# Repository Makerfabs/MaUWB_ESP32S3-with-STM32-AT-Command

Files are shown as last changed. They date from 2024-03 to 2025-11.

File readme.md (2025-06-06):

# MaUWB_ESP32S3 with STM32 AT Command

```

Version:    V1.1
Author:     Vincent
Create Date:    2024/3/12
Note:

        2024/9/24  V1.1: MaUWB(v1.1.1).HEX is released to support simultaneous data transmission for ranging. 

```


[toc]

# Makerfabs

[Makerfabs home page](https://www.makerfabs.com/)

[Makerfabs Wiki](https://wiki.makerfabs.com/)

# MaUWB_ESP32S3 with STM32 AT Command
## Intruduce

Product Link ：[MaUWB_ESP32S3 with STM32 AT Command]() 

Wiki Link : []()

The latest UWB module that solves multiple anchors& tags mutual conflicts, support max 8 Anchors + 64 tags in application, to create a multi-anchor multi-tag positioning system, and add the ability to set the Anchor antenna delay

## Feature

- DW3000 with PA, max range 500M
- Precision 0.5M(in range 100m)
- Support 8 anchors+ 64 Tags application

# Code

## AT Command Usage

Please refer to the AT Command manual for detailed use.

hardware\Makerfabs UWB AT Module AT Command Manual(v1.0.5).pdf

### Initial configuration

You are advised to use serial_test.ino to configure the UWB AT module.
Each time you configure the UWB AT module, follow the following configuration sequence:

```C 

AT?

//Test whether the serial port communication is normal

AT+RESTORE

//Restore factory Settings

AT+SETCFG=(x1),(x2),(x3),(x4)
// Such as: AT+SETCFG=0,1,0,1

//Set the role and frequency
//More on that later

AT+SETCAP=10,15

//Set the capacity and send time slot

AT+SETRPT=1

// Turn on automatic reporting

AT+SAVE

// Save

AT+RESTART

// Restart

```

### Set the role and frequency

AT+SETCFG=(x1),(x2),(x3),(x4)

Parameter description

x1: Device ID(Note: Base station 0-7, label 0-63)

x2: Device role (0: tag /1: base station)

x3: device air speed (0:850K/1:6.8M, default :6.8M)

x4: Range filtering enabled (0: off /1: on)

Generally, 850K is used and distance filtering is turned on.

```c
//Example
//A0
AT+SETCFG=0,1,0,1

//A1
AT+SETCFG=1,1,0,1

//A2
AT+SETCFG=2,1,0,1

//A3
AT+SETCFG=3,1,0,1

//T0
AT+SETCFG=0,0,0,1

//T1
AT+SETCFG=1,0,0,1

//T2
AT+SETCFG=2,0,0,1

//T3
AT+SETCFG=3,0,0,1

//T4
AT+SETCFG=4,0,0,1

//T5
AT+SETCFG=5,0,0,1

```

## Compiler Options

- Use type-c use cable connect USB-TTL to PC.
- Select "ESP32S3 DEV Module"

Libraries:
- Use 2.0.0   Wire
- Use 1.11.7   Adafruit_GFX_Library
- Use 1.14.4   Adafruit_BusIO
- Use 2.0.0   SPI
- Use 2.5.7   Adafruit_SSD1306

## Example

### esp32_at

Factory firmware, reset the UWB AT module and set it to Tag 0.

# AT Module Firmware Update

Connect ST-Link to PC.

Open STM32 ST-LINK Utility.
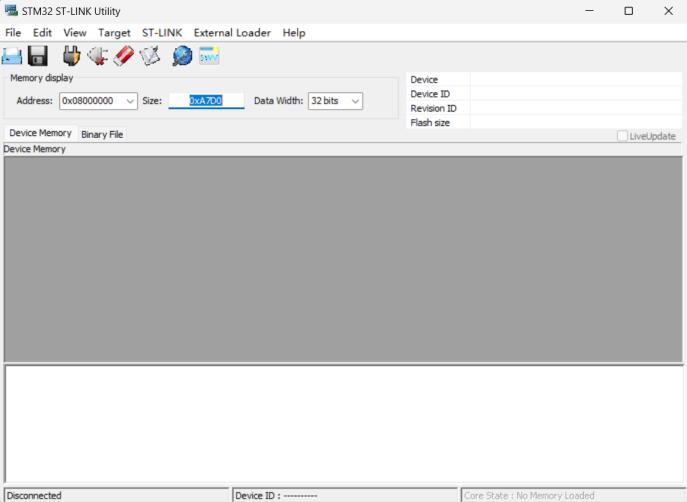
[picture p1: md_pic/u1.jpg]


Open "Target/Settings", it should display ST-Link Serial Number.
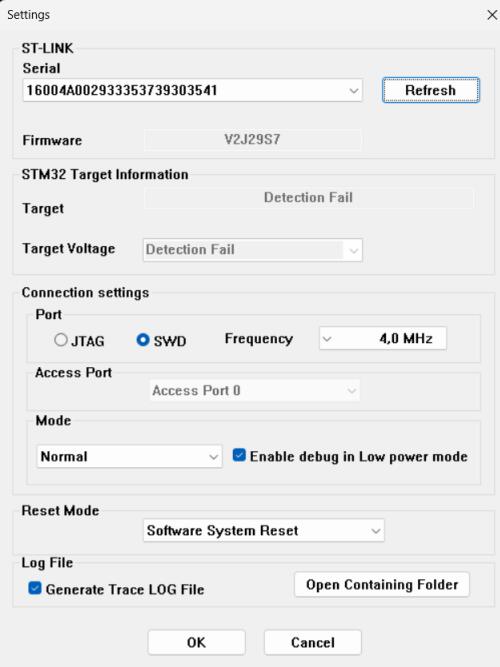
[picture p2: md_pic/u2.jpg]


Close the window, back to main page.

Connect ST-Link and MaUWB.

And use TypeC cable power on MaUWB, the power of ST-Link is not enough.

Like this:

|ST-LINK|3v3|clk|dio|gnd|
|----|----|----|----|----|
|UWB_AT|3.3v|swclk|swdio|gnd|

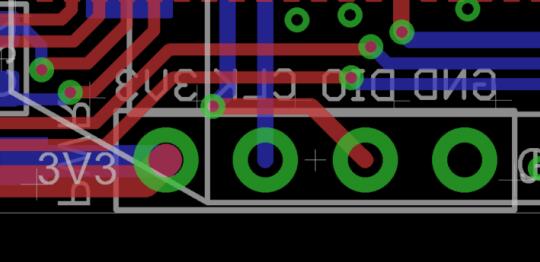
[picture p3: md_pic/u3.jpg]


Click "connect to target", it should be display device type. And click "Program verify".

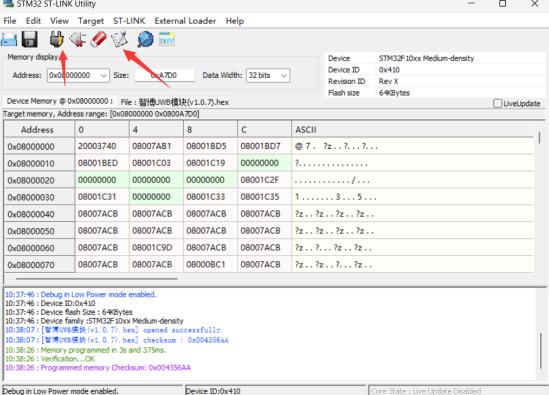
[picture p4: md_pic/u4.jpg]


Select hex file, click "START" to download.

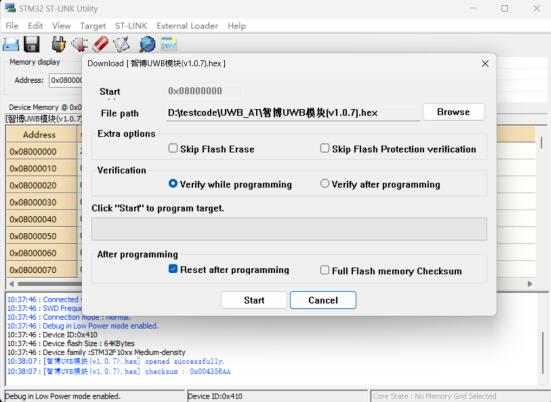
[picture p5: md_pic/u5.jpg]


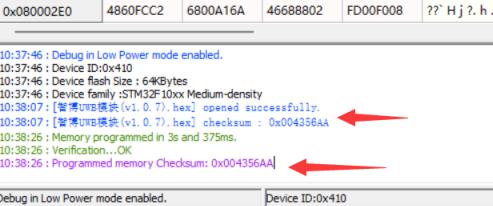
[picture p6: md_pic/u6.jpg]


# STM32 Pin Map

STM32F103T8U6

|Index|STM32|PINOUT|Function|
|----|----|----|----|
|1|PA0|DW_RSTn|Reset pin. Active Low Output.|
|2|PA4|DW_CSn|SPI chip select|
|3|PA5|DW_SLK|SPI clock|
|4|PA6|DW_MISO|SPI data output|
|5|PA7|DW_MOSI|SPI data input.|
|6|PA8|DW_EXTON|External device enable. Asserted during wake up process and held active until device enters sleep mode. Can be used to control external DC-DC converters or other circuits that are not required when the device is in sleep mode so as to minimize power consumption.|
|7|PB0|DW_wakeup|When asserted into its active high state, the WAKEUP pin brings the DW3000 out of SLEEP or DEEPSLEEP states into operational mode|
|8|PB5|DW_IRQn|Interrupt Request output from the DW3000 to the host processor. By default IRQ is an active-high output but may be configured to be active low if required. For correct operation in SLEEP and DEEPSLEEP modes it should be configured for active high operation. This pin will float in SLEEP and DEEPSLEEP states and may cause spurious interrupts unless pulled low. When the IRQ functionality is not being used the pin may be reconfigured as a general purpose I/O line, GPIO8.|
|10|PA1|LED_RUN|Indicator output pin|
|11|PA9|USART1_TX|
|12|PA10|USART1_RX|
|13|PA13|SWDIO|
|14|PA14|SWCLK|

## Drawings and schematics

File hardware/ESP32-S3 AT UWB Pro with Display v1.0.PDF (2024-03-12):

## USB

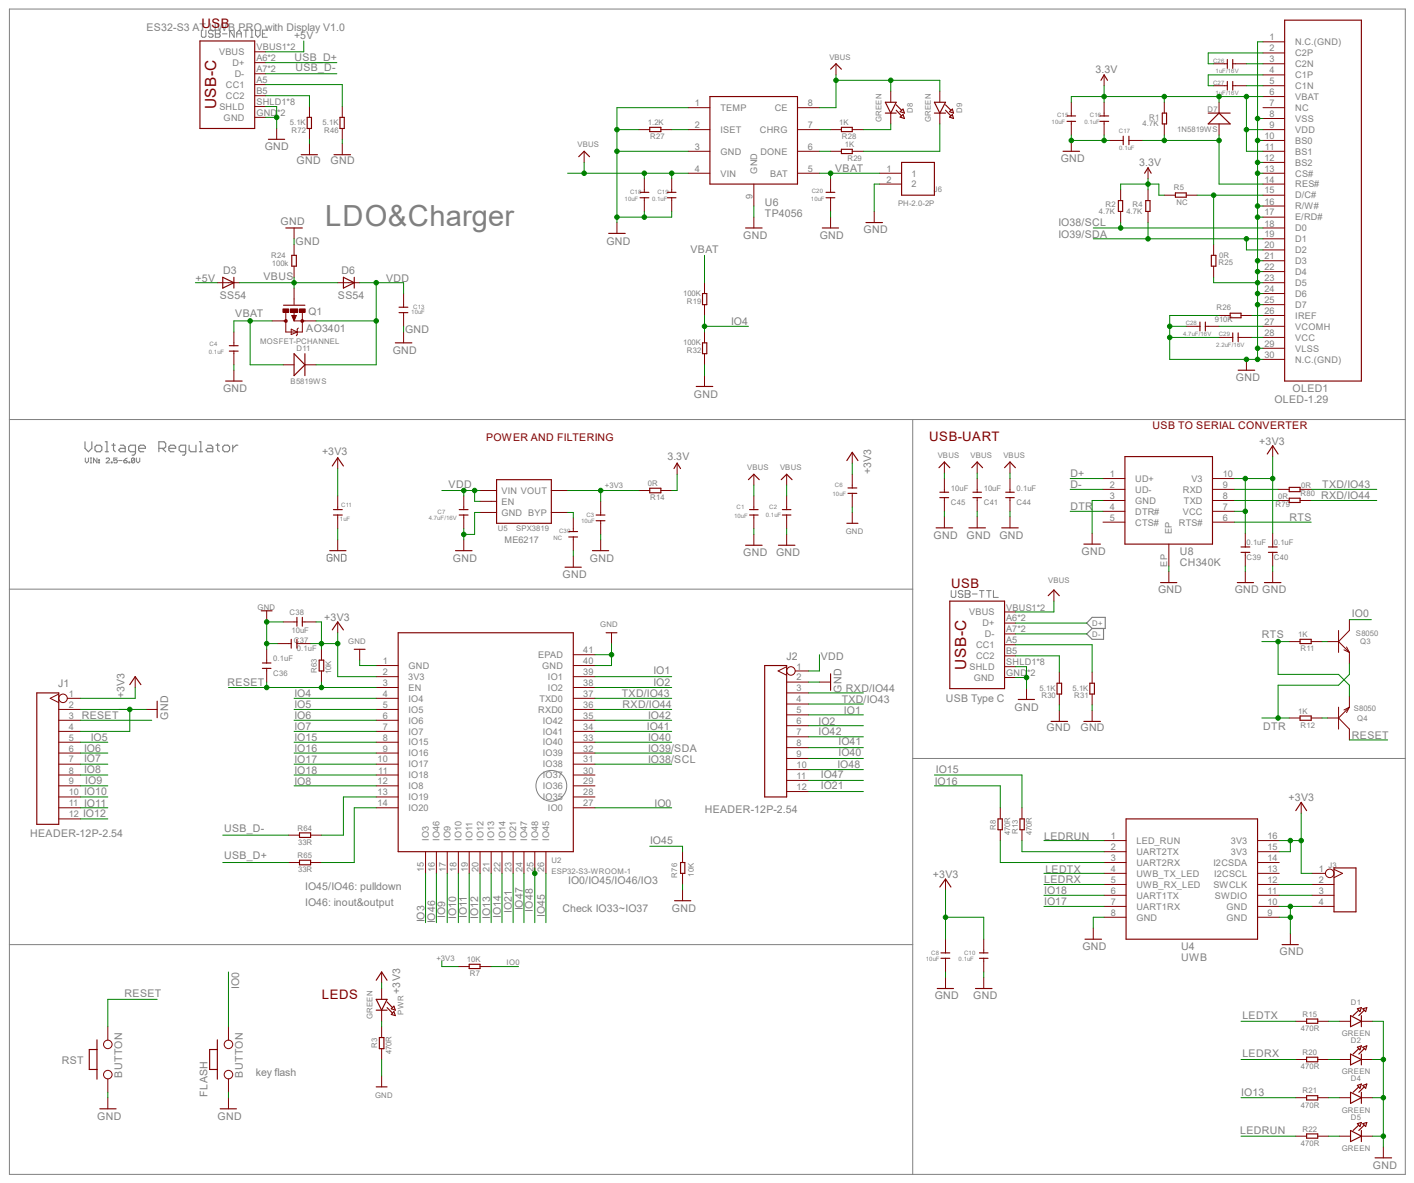
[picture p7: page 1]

ES32-S3 AT UWB PRO with Display V1.0

USB TO SERIAL CONVERTER USB⁻C USB⁻C

D1 19
D2 20

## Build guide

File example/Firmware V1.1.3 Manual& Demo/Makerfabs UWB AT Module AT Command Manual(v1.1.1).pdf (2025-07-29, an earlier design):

# Makerfabs UWB AT Module

# AT Command Manual

V1.1.1

Author：Yuki

Time：2025/07/29

Date | Versions | Description | Author
20230815 | v1.0.0 | Introduction to Use & Function | Jerry
20230823 | V1.0.1 | 1) Correct clerical errors 2) Anchor&Tag Software integration 3) Improve the Run Led pin description 4) Improve the Tx Led pin description 5) Improve the Rx Led pin description 6) Improved UART2 RX /RESET /WAKEUP pin description | Jerry
20230829 | V1.0.2 | 1) Add frequency option for 850K rate 2) Modify the boot log 3) Modify command，AT+SETCFG 4) Modify command，AT+GETCFG? 5) Modify command，AT+RANGE | Jerry
20230926 | V1.0.3 | 1) Improve documentation 2) Add hardware application circuits | Jerry
20230926 | V1.0.4 | 1) Added package size diagram | Jerry
20231013 | V1.0.5 | First edition of translation | Vincent
20240227 | V1.0.6 | The maximum number of labels increased to 64 | Vincent
20240315 | V1.0.7 | second edition of translation | Carla
20240920 | V1.0.8 | 1)Modify command，AT+SETCAP 2)Modify command，AT+GETCAP 3)Add command，AT+SETPOW | Yuki

| | 4)Add command，AT+GETPOW? 5)Add command，AT+DATA 6)Add command，AT+RDATA
20250227 | V1.0.9 | 1)Add command，AT+SETPAN 2)Add command，AT+GETPAN? | Yuki
20250707 | V1.1.0 | 1)Firmware MaUWB(v1.1.3) add functions: Anchor capacity expanded from 8 to unlimited, supporting multi-zone positioning. (Tags can now automatically detect and select the 8 nearest Anchors from a larger pool of deployed Anchors) 2)Modify command，AT+RANGE 3)Add command note， AT+GETCAP/ AT+GETCAP? 4)Add command note，AT+SETCFG / AT+GETCFG? 5)Add command default value，AT+GETCFG? / AT+GETANT? / AT+GETCAP? / AT+GETRPT? / AT+GETPOW? / AT+GETPAN? | Yuki
20250729 | V1.1.1 | Modify the error description to change the supported number of Anchors to "unlimited". | Yuki

Contents

# 1 Product description

## 1.1 Introduction

This module describes the high-precision real-time positioning module developed by our company based on Qorvo DW3000 series chips. The module integrates MCU and all RF circuits, antennas, power management and clock circuits. The module can be quickly configured and used

by AT command. The target readers are software and hardware engineers, UWB learners and users. This module is based on TOF (TWR) two-sided distance measurement and a variety of filtering algorithms to achieve distance calculation. After combination and collocation between multiple modules, it can be adapted to most of the location application scenarios, which is convenient for users to learn and research and rapid product application. Its ranging accuracy may be less than 10cm; And the module supports data transfer rates of up to 6.8Mbps. 1.2 Feature

1) Comply with IEEE802.15.4-2011 ultra-wideband standard;
2) Easy to integrate without additional RF design;
3) Support CH5 (6489.6MHZ) RF band;
4) Strong resistance to multi-path fading;
5) Two modes of data transmission rate of 850kbps and 6.8Mbps;
6) The maximum packet length is 1023 bytes, which meets the application requirements of high data volume exchange;
7) The system supports unlimited Anchor 64 tags. 8) The module supports free configuration of refresh rate, up to 100Hz;
9) Module serial port communication baud rate 115200;
10) Module (Tag) deep hibernation working current as low as 35uA, working current 34mA;
11) Support AT command;

## 1.3 Functional block diagram

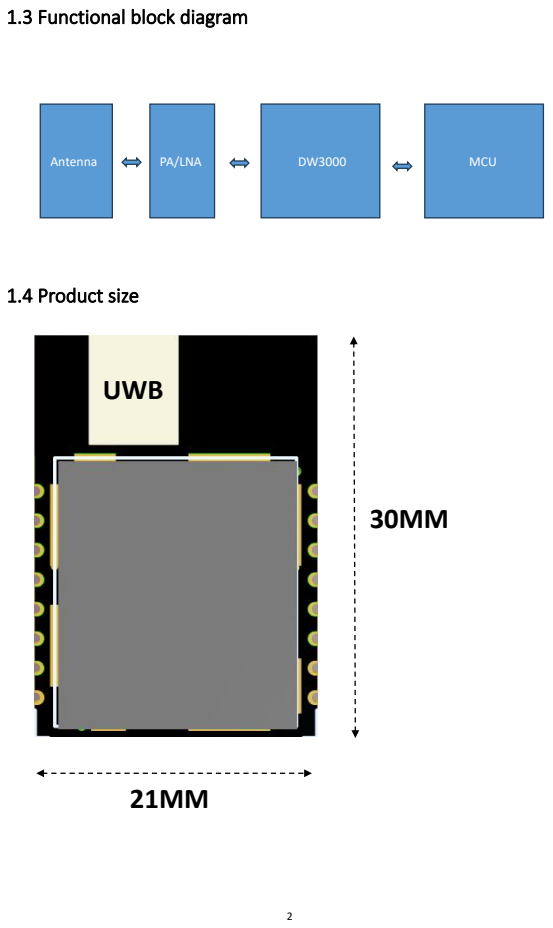
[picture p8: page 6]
1.4 Product size; PA/LNA; MCU; UWB; Antenna

# 2 Module hardware description

## 2.1 Module hardware pin definition

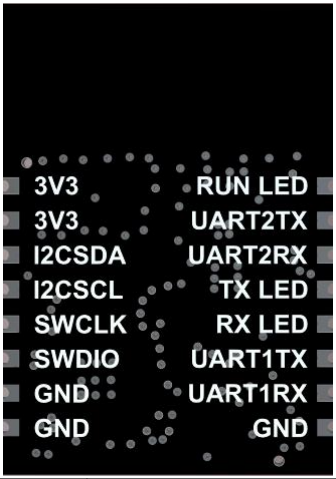
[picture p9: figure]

Index | Pin | Function
1 | 3V3 | Power 3.3v
2 | 3V3 | Power 3.3v
3 | I2CSDA | Reserve pin(NC)
4 | I2CSCL | Reserve pin(NC)
5 | SWCLK | Module download port
6 | SWDIO | Module download port

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
7 | GND | GND
8 | GND | GND
9 | RUN LED | Module running indicator,Anchor/Tag universal (except for Tag entering Sleep) Configuration status: Blinking slowly (1 second) Working status: Blinking at short intervals (0.1 seconds)
10 | UART2 TX | Reserve pin(NC)
11 | UART2 RX/RESET/WAKEUP | Function 1: Pull down 3 seconds reset (reset function) Function 2: Tag low power state, pull down any time to wake up (wake up function, only valid Tag)
12 | TX LED | Module UWB transmit indicator (Anchor valid,Tag invalid)
13 | RX LED | Module UWB acceptance indicator (Anchor valid,Tag invalid)
14 | UART1 TX | Module serial TX port
15 | UART1 RX | Module serial RX port
16 | GND | GND

## 2.2 Module hardware package size

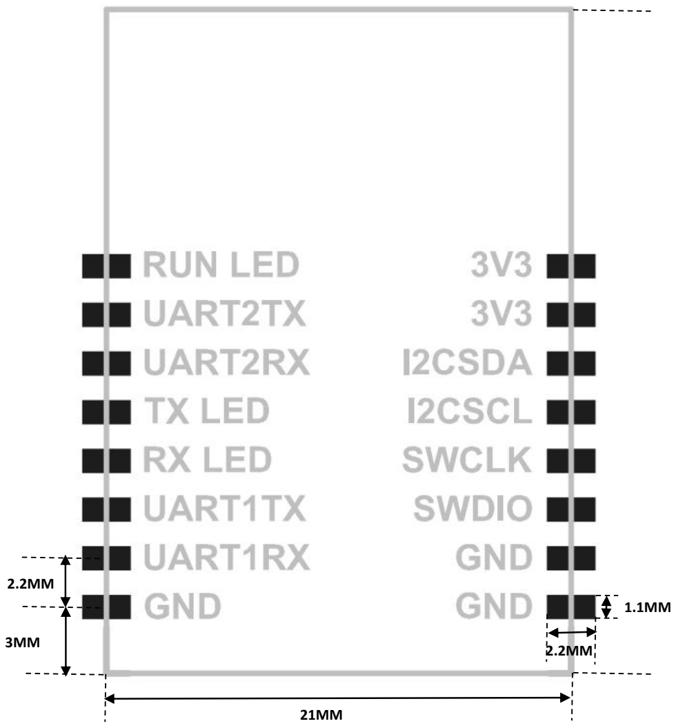
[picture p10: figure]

30MM

## 2.3 Power interface

Index | Pin | Function
1 2 | 3V3 | Power supply 3.3V (Note: If the power supply voltage exceeds 3.3, the module will be damaged)
7 8 16 | GND | GND

lDO voltage regulator chip is used to increase 100UF tantalum capacitor and

100NF capacitor to stabilize voltage and reduce interference caused by power

supply.

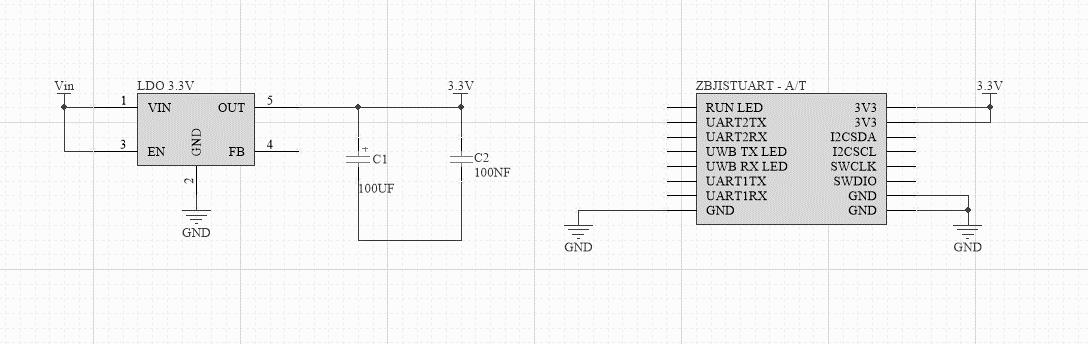
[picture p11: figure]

## 2.4 UART application circuit

Index | Pin | Function
14 | UART1 TX | Module TX
15 | UART1 RX | Module RX

Serial port communication level is 3.3VTTL, different level systems should do

level matching.

## 2.5 LED application circuit

Index | Pin | Function
9 | RUN LED | Module running indicator,Anchor/Tag universal (except for Tag entering Sleep) Configuration status: Blinking slowly (1 second) Working status: Blinking at short intervals (0.1 seconds)
12 | TX LED | Module UWB transmit indicator (Anchor valid,Tag invalid)
13 | RX LED | Module UWB acceptance indicator (Anchor valid,Tag invalid)

LED output High level LED is on, low level LED is off.

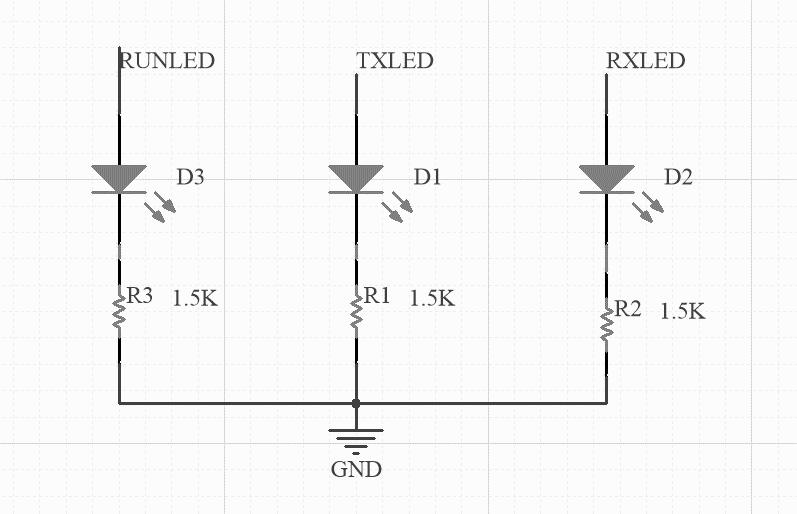
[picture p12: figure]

## 2.6 Reset interface

Index | Pin | Function
11 | UART2 RX/RESET/WAKEUP | 1: Pull down 3 seconds reset (reset function) 2: Label low power state, pull down any time to wake up (wake up function, only valid label)

It is recommended to use an open set or open drain drive circuit to control RESET.

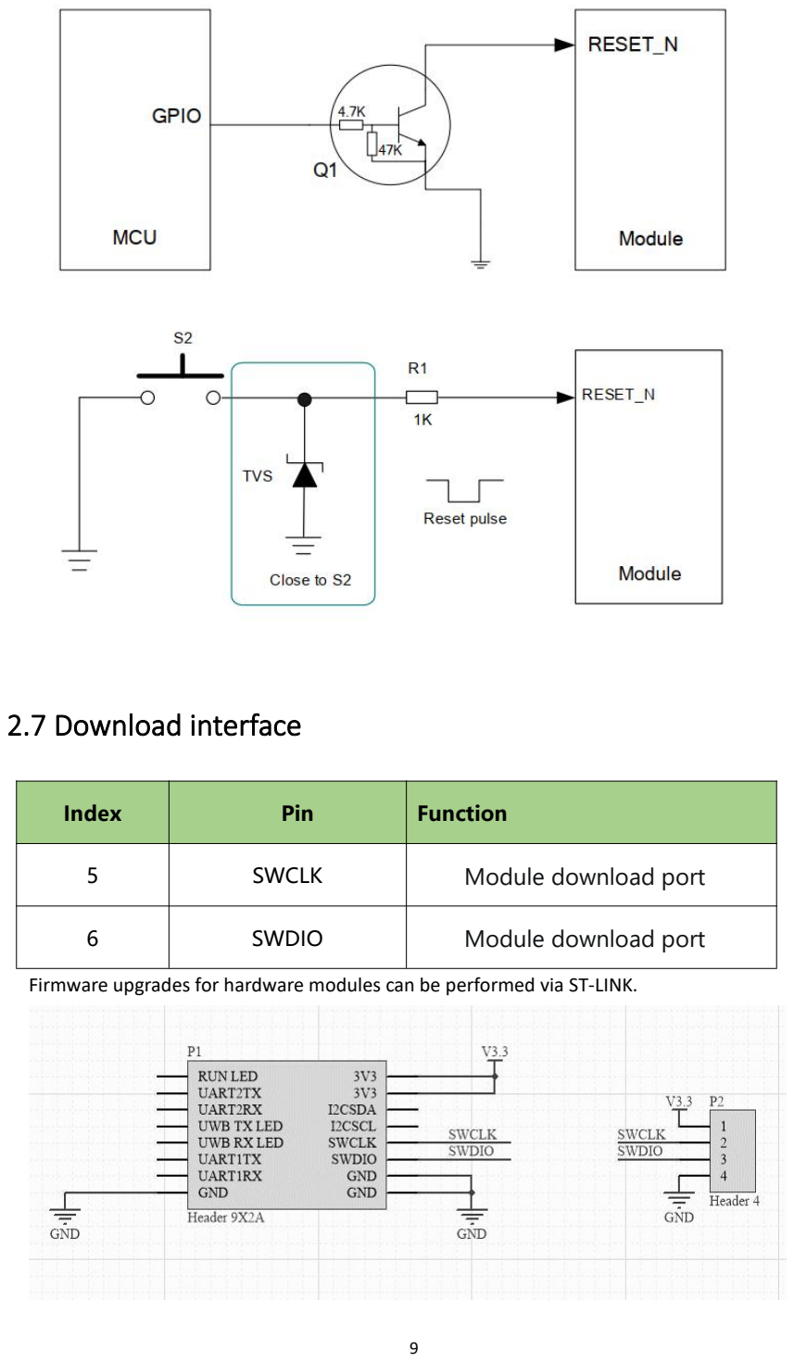
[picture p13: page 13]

## 2.7 Download interface

Index | Pin | Function
5 | SWCLK | | Module download port
6 | SWDIO | | Module download port

Firmware upgrades for hardware modules can be performed via ST-LINK.

# 3 Description of the module AT

# command

## 3.1 Command summary description

Index | Command | Function | Role
1 | AT? | Serial port test | Tag/Anchor
2 | AT+GETVER? | Get version | Tag/Anchor
3 | AT+RESTART | Restart module | Tag/Anchor
4 | AT+RESTORE | Restore configuration | Tag/Anchor
5 | AT+SAVE | Save configuration | Tag/Anchor
6 | AT+SETCFG | Set role message | Tag/Anchor
7 | AT+GETCFG? | Get role message | Tag/Anchor
8 | AT+SETANT | Set antenna delay | Tag/Anchor
9 | AT+GETANT? | Get antenna delay | Tag/Anchor
10 | AT+SETCAP | Set the Anchor/Tag capacity of the system | Tag/Anchor
11 | AT+GETCAP? | Get the Anchor/Tag capacity of the system | Tag/Anchor
12 | AT+SETRPT | Set the automatic reporting status | Tag/Anchor
13 | AT+GETRPT? | Get the automatic reporting status | Tag/Anchor
14 | AT+RANGE | Active reporting command | Tag/Anchor

15 | AT+SLEEP | Sleep command | Tag
16 | AT+SETPOW | Configuration of the device's transmission power. | Tag/Anchor
17 | AT+GETPOW? | Get device transmit power | Tag/Anchor
18 | AT+DATA | Transparent data transmission, supporting up to 32 bytes of data transfer. | Tag/Anchor
19 | AT+RDATA | | Tag/Anchor
20 | AT+SETPAN | Used to differentiate between different networks, if shared by more than one system, use this field for differentiation. | Tag/Anchor
21 | AT+GETPAN? | Used to differentiate between different networks, if shared by more than one system, use this field for differentiation. | Tag/Anchor

## 3.2 Command：AT?

Command | AT?

Parameter

Return

Example | AT? OK
Function | Verify that the serial port communication of the module is normal

## 3.3 Command：AT+GETVER?

Command | AT+GETVER?

Parameter

Return | x1: indicates the software version x2: Hardware version
Example | AT+GETVER? AT+GETVER=software:v01_00_000,hardware:v01_03_000
Function | Obtain the module software version and hardware version

## 3.4 Command：AT+RESTART

Command | AT+RESTART

Parameter

Return

Example | AT+RESTART OK
Function | Reset module

## 3.5 Command：AT+RESTORE

Command | AT+RESTORE

Parameter

Return

Example | AT+RESTORE OK
Function | Restore factory mode (clear all configuration information)

## 3.6 Command：AT+SAVE

Command | AT+SAVE

Parameter

Return

Example | AT+SAVE OK
Function | Save the configuration parameters (after configuring the information, be sure to save and write to the flash)

## 3.7 Command：AT+SETCFG

Command | AT+SETCFG=(x1),(x2),(x3),(x4)
Parameter | x1:Device ID(Anchor 0-unlimited，Tag 0-63) x2:Device Role(0:Tag / 1:Anchor) x3:Equipment communication rate(0:850K/1:6.8M) x4:Range filtering is enabled(0:Close / 1:Open) Note: If the user intends to implement multi-zone positioning, it is recommended to use 6.8Mbps data rate and close the distance filtering function. Return
Example | AT+SETCFG=0,1,1,1 OK
Function | Set basic module parameters

## 3.8 Command：AT+GETCFG?

Command | AT+GETCFG?

Parameter

Return | x1:Device ID(Anchor 0-unlimited，Tag 0-63, Default:-1) x2:Device Role(0:Tag / 1:Anchor / -1:Not set, Default:-1) x3:Equipment communication rate(0:850K / 1:6.8M, Default:1) x4:Range filtering is enabled(0:Close / 1:Open, Default:1) Note: If the user intends to implement multi-zone positioning, it is recommended to use 6.8Mbps data rate and close the distance filtering function. Example
| AT+GETCFG? AT+GETCFG=-1,-1,1,1
Function | Obtain basic module parameters

## 3.9 Command：AT+SETANT

Command | AT+SETANT=(x1)
Parameter | x1:Device antenna delay

Return

Example | AT+SETANT=16536 OK
Function | Set module antenna delay (antenna delay is used to: calibrate distance values)

## 3.10 Command：AT+GETANT?

Command | AT+GETANT?

Parameter

Return | x1:Device antenna delay (Default:16336)
Example | AT+GETANT? AT+GETANT=16336
Function | Get module antenna delay (antenna delay for: calibrating distance values)

## 3.11 Command：AT+SETCAP

Command | AT+SETCAP=(x1),(x2),(x3)
Parameter | x1:Tag capacity (default: 10, maximum: 64) x2:Time of a single time slot (6.8M not less than 10ms,850K not less than 15ms) X3:extMode, whether to increase the passthrough command when transmitting (0: normal packet when communicating, 1: extended packet when communicating) time 25ms for extended packet. (Note:850K currently does not support extended data packet.)

6.8M, Minimum single slot time 10ms for normal packet, Minimum single slot time 10ms for extended packet. 850K. Minimum single slot time 15ms for normal packet, Minimum single slot

| (Note: The refresh rate relationship is as follows: label capacity x single slot time, Example 1: If x1=10 and x2=10, the refresh rate is 10Hz Example 2: If x1=5 and x2=10, the refresh rate is 20Hz Example 3: x1=1 x2=10, then refresh rate = 100Hz)

Return

Example | AT+SETCAP=10,10,1 OK
Function | Set system base station/label capacity (refresh rate)/Whether the transmitted packet is in extended mode

## 3.12 Command：AT+GETCAP?

Command | AT+GETCAP?

Parameter

Return

x1:Tag capacity (default: 10, maximum: 64)
x2: Time of a single time slot (6.8M not less than 10ms,850K not less than 15ms, default: 10)

X3:extMode, whether to increase the passthrough command when transmitting (0: normal packet when communicating, 1: extended packet when communicating, default: 0)

6.8M, Minimum single slot time 10ms for normal packet, Minimum single slot time 10ms for extended packet. 850K. Minimum single slot time 15ms for normal packet, Minimum single slot

time 25ms for extended packet. (Note:850K currently does not support extended data packet.)

(Note: The refresh rate relationship is as follows: label capacity x single slot time, Example 1: If x1=10 and x2=10, the refresh rate is 10Hz

Example 2: If x1=5 and x2=10, the refresh rate is 20Hz
Example 3: x1=1 x2=10, then refresh rate = 100Hz)
Example | AT+GETCAP? AT+GETCAP=10,10,0
Function | Get system base station/label capacity (refresh rate)/Whether the transmitted packet is in extended mode

## 3.13 Command：AT+SETRPT

Command | AT+SETRPT=(x1)
Parameter | x1: Whether the report is reported automatically (0: off 1: on)

Return

Example | AT+SETRPT=1 OK
Function | Enable whether the module actively reports distance data. 3.14 Command：AT+GETRPT?
Command | AT+GETRPT?
Parameter | x1: Whether the report is reported automatically (0: off 1: on, default: 1)

Return

Example | AT+GETRPT? AT+GETRPT=1
Function | Enable whether the module actively reports distance data. 3.15 Command：AT+RANGE
Command | AT+RANGE=tid:x1,mask:x2,seq:x3,range:(x4,x5,x6,x7,x8,x9,x10,x11), rssi:(x12,x13,x14,x15,x16,x17,x18,x19), ancid:(x20,x21,x22,x23,x24,x25,x26,x27)

Parameter

Return | tid:x1(Tag ID, in decimal format) mask:x2(Significance bit, in hexadecimal format) seq:x3(Tag communication sequence, in decimal format) range0:x4(The distance from Tag to Abchor0 ,in cm, in decimal format) range1:x5(Tag to Anchor 1) range2:x6(Tag to Anchor 2) range3:x7(Tag to Anchor 3) range4:x8(Tag to Anchor 4)

range5:x9(Tag to Anchor 5) range6:x10(Tag to Anchor 6)
range7:x11(Tag to Anchor 7)

rssi0:x12(Signal strength value from Tag to Anchor 0, in dBm, floating point type) rssi1:x13(Signal strength value from Tag to Anchor 1)
rssi2:x14(Signal strength value from Tag to Anchor 2)
rssi3:x15(Signal strength value from Tag to Anchor 3)
rssi4:x16(Signal strength value from Tag to Anchor 4) rssi5:x17(Signal strength value from Tag to Anchor 5) rssi6:x18(Signal strength value from Tag to Anchor 6)
rssi7:x19(Signal strength value from Tag to Anchor 7)

ancid0:x20(Device ID of the Tag to Anchor 0, configured via the SETCFG command)
ancid0:x20(Device ID of the Tag to Anchor 0)
Ancid1:x21(Device ID of the Tag to Anchor 1)
Ancid2:x22(Device ID of the Tag to Anchor 2) Ancid3:x23(Device ID of the Tag to Anchor 3) Ancid4:x24(Device ID of the Tag to Anchor 4) Ancid5:x25(Device ID of the Tag to Anchor 5) Ancid6:x26(Device ID of the Tag to Anchor 6) Ancid7:x27(Device ID of the Tag to Anchor 7)
Example | AT+RANGE=tid:2,timer:1166463,timerSys:753058,mask:12,seq:11, range:(0,105,0,0,71,0,0,0), rssi:(0.00,-81.50,0.00,0.00,-80.70,0.00,0.00,0.00), ancid:(0,25,0,0,28,0,0,0)
Function | After the 3.12 command is set, the distance value is actively reported (common to
Tag and Anchor). 3.16 Command：AT+SLEEP
Command | AT+SLEEP=(x1)
Parameter | x1: Sleep time(Unit : ms)[Range: 0-65535,65535=Forever] (Wake up mode: ① serial port wake up (send any data) ②UART2 RX drop-down wake up at any time)
Return | OK
Example | AT+SLEEP=1000 OK

Function Set the device sleep time (valid for Tags only)

## 3.17 Command：AT+SETPOW

Command | AT+SETPOW=(x1)
| x1:Transmit Power Gain Configuration(Default FD, generally does not need to be modified) ①Gain Register
7 | 6 | 5 | 4 | 3 | 2 | 1 | 0
Fine Gain,Total 64 | | | | | | Coarse Gain,Total 4

Parameter

②Gain Diagram

Return

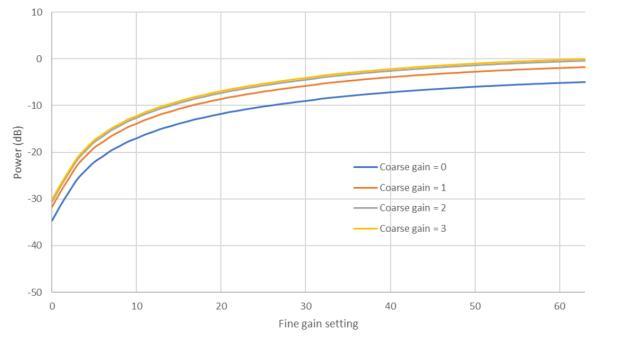
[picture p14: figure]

Example | AT+SETPOW=FD OK
Function | Configuration of the device's transmission power. 3.18 Command：AT+GETPOW?
Command | AT+GETPOW?

Parameter

Return | Default:FD
Example | AT+GETPOW? AT+GETPOW=FD

Function Get device transmit power

## 3.19 Command：AT+DATA

Command | AT+DATA=(x1),(x2)
Parameter | x1:Length of transmitted data x2:Transmitted data This command can be used if the device has an extMode of 1. Return

Example

AT+DATA=10,1234567890
OK
Function | Transmitted data, supporting up to 32 bytes of data transfer. 3.20 Command：AT+RDATA
Command | AT+RDATA=(x1),(x2),(x3),(x4),(x5)

Parameter

Return | x1: Tag or Anchor x2: Anchor or Tag address x3: Device Local Time x4: Length of transmitted data x5: Transmitted data

Example

Function

## 3.21 Command：AT+SETPAN

Command | AT+SETPAN=(x1)
Parameter | x1: Network ID (Only the same network ID can communicate)

Return

Example | AT+SETPAN=1234 OK
Function | Used to differentiate between different networks, if shared by more than one
system, use this field for differentiation. 3.22 Command：AT+GETPAN?
Command | AT+GETPAN?

Parameter

Return | Default:1111
Example | AT+GETPAN? AT+GETPAN=1111
Function | Used to differentiate between different networks, if shared by more than one system, use this field for differentiation.

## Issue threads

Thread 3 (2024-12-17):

The ESP32 on the actual board does not match the one shown in the schematic diagram.

L-lorish, 2024-12-17:
Why is there a discrepancy? Can the code still run properly based on the design in the schematic diagram?

Closed 2024-12-21.

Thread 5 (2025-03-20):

I2C issue

nowdeprecated, 2025-03-20:
Using the provided sketch I get the errors below on multiple hardware units:

(1007) i2c.master: I2C transaction unexpected nack detected
(1008) i2c.master: s_i2c_synchronous_transaction(924): I2C transaction failed
(1009) i2c.master: i2c_master_multi_buffer_transmit(1186): I2C transaction failed

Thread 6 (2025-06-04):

Development Board Size

obitvn, 2025-06-04:
Hi Makerfabs, can you share the 3D file or board size file? We plan to buy 100 tags and need to prepare the case and frame for these boards.

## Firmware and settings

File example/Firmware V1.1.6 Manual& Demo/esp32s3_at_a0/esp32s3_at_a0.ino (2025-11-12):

/*
For ESP32S3 UWB AT Demo


Use 2.0.0   Wire
Use 1.11.7   Adafruit_GFX_Library
Use 1.14.4   Adafruit_BusIO
Use 2.0.0   SPI
Use 2.5.7   Adafruit_SSD1306

*/

//去掉DTR脚串口， 否则一直拉低复位脚

// User config          ------------------------------------------

#define UWB_INDEX 0

#define PAN_INDEX 0

#define ANCHOR

#define UWB_TAG_COUNT 1

// User config end       ------------------------------------------

#include <Wire.h>
#include <Adafruit_GFX.h>
#include <Adafruit_SSD1306.h>
#include <Arduino.h>

#define SERIAL_LOG Serial
#define SERIAL_AT mySerial2

HardwareSerial SERIAL_AT(2);

// ESP32S3
#define RESET 16

#define IO_RXD2 18
#define IO_TXD2 17

#define I2C_SDA 39
#define I2C_SCL 38

Adafruit_SSD1306 display(128, 64, &Wire, -1);

void setup()
{
    pinMode(RESET, OUTPUT);
    digitalWrite(RESET, HIGH);

    SERIAL_LOG.begin(250000);

    SERIAL_LOG.print(F("Hello! ESP32-S3 AT command V1.0 Test"));
    SERIAL_AT.begin(115200, SERIAL_8N1, IO_RXD2, IO_TXD2);

    SERIAL_AT.println("AT");
    Wire.begin(I2C_SDA, I2C_SCL);
    delay(1000);
    // SSD1306_SWITCHCAPVCC = generate display voltage from 3.3V internally
    if (!display.begin(SSD1306_SWITCHCAPVCC, 0x3C))
    { // Address 0x3C for 128x32
        SERIAL_LOG.println(F("SSD1306 allocation failed"));
        for (;;)
            ; // Don't proceed, loop forever
    }
    display.clearDisplay();

    logoshow();

    sendData("AT?", 2000, 1);
    sendData("AT+RESTORE", 5000, 1);

    sendData(config_cmd(), 2000, 1);
    sendData(cap_cmd(), 2000, 1);
//    sendData("AT+GETCAP?/r/n", 2000, 1);
    sendData("AT+SETRPT=1", 2000, 1);
    sendData(Pan_cmd(), 2000, 1);    
    sendData("AT+SAVE", 2000, 1);
    sendData("AT+RESTART", 2000, 1);
}

long int runtime = 0;

String response = "";
//String rec_head = "AT+RANGE";

void loop()
{

    // put your main code here, to run repeatedly:
    while (SERIAL_LOG.available() > 0)
    {
        SERIAL_AT.write(SERIAL_LOG.read());
        yield();
    }
    while (SERIAL_AT.available() > 0)
    {
        char c = SERIAL_AT.read();

        if (c == '\r')
            continue;
        else if (c == '\n' || c == '\r')
        {
            SERIAL_LOG.println(response);

            response = "";
        }
        else
            response += c;
    }
}

// SSD1306

void logoshow(void)
{
    display.clearDisplay();

    display.setTextSize(1);              // Normal 1:1 pixel scale
    display.setTextColor(SSD1306_WHITE); // Draw white text
    display.setCursor(0, 0);             // Start at top-left corner
    display.println(F("MaUWB DW3000"));

    display.setCursor(0, 20); // Start at top-left corner
    // display.println(F("with STM32 AT Command"));

    display.setTextSize(2);

    String temp = "";

    temp = temp + "A" + UWB_INDEX;

    temp = temp + "   6.8M";
    
    display.println(temp);

    display.setCursor(0, 40);

    temp = "Total: ";
    temp = temp + UWB_TAG_COUNT;
    display.println(temp);

    display.display();

    delay(2000);
}

String sendData(String command, const int timeout, boolean debug)
{
    String response = "";
    // command = command + "\r\n";

    SERIAL_LOG.println(command);
    SERIAL_AT.println(command); // send the read character to the SERIAL_LOG

    long int time = millis();

    while ((time + timeout) > millis())
    {
        while (SERIAL_AT.available())
        {

            // The esp has data so display its output to the serial window
            char c = SERIAL_AT.read(); // read the next character.
            response += c;
        }
    }

    if (debug)
    {
        SERIAL_LOG.println(response);
    }

    return response;
}

String config_cmd()
{
    String temp = "AT+SETCFG=";

    // Set device id
    temp = temp + UWB_INDEX;
    
    // Set device role
    //x2:Device Role(0:Tag / 1:Anchor)
    temp = temp + ",1";


    // Set frequence 850k or 6.8M(0:850K/1:6.8M

    temp = temp + ",1";

    // Set range filter 0:close/1:open  (multi-location fuction must close range filter)
    temp = temp + ",0";

    return temp;
}

String cap_cmd()
{
    String temp = "AT+SETCAP=";

    // Set Tag capacity
    temp = temp + UWB_TAG_COUNT;

    //  Time of a single time slot  6.5M : 10MS  850K ： 15MS
    temp = temp + ",10";
    
    //X3:extMode, whether to increase the passthrough command when transmitting
    //(0: normal packet when communicating, 1: extended packet when communicating)
    temp = temp + ",1";

    return temp;
}

String Pan_cmd()
{
    String temp = "AT+SETPAN=";

    temp = temp + PAN_INDEX;

    return temp;
}

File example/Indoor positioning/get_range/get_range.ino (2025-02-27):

/*
For ESP32 UWB AT Demo
*/

#include <Wire.h>
#include <Adafruit_GFX.h>
#include <Adafruit_SSD1306.h>
#include <Arduino.h>

HardwareSerial mySerial2(2);

#define RESET 16

#define IO_RXD2 18
#define IO_TXD2 17

#define I2C_SDA 39
#define I2C_SCL 38

Adafruit_SSD1306 display(128, 64, &Wire, -1);

void setup()
{
    pinMode(RESET, OUTPUT);
    digitalWrite(RESET, HIGH);

    Serial.begin(115200);

    Serial.print(F("Hello! ESP32-S3 AT command V1.0 Test"));
    mySerial2.begin(115200, SERIAL_8N1, IO_RXD2, IO_TXD2);

    mySerial2.println("AT");
    Wire.begin(I2C_SDA, I2C_SCL);
    delay(1000);
    // SSD1306_SWITCHCAPVCC = generate display voltage from 3.3V internally
    if (!display.begin(SSD1306_SWITCHCAPVCC, 0x3C))
    { // Address 0x3C for 128x32
        Serial.println(F("SSD1306 allocation failed"));
        for (;;)
            ; // Don't proceed, loop forever
    }
    display.clearDisplay();

    logoshow();
}

long int runtime = 0;

String response = "";
String rec_head = "AT+RANGE";

void loop()
{

    // put your main code here, to run repeatedly:
    while (Serial.available() > 0)
    {
        mySerial2.write(Serial.read());
        yield();
    }
    while (mySerial2.available() > 0)
    {
        char c = mySerial2.read();

        if (c == '\r')
            continue;
        else if (c == '\n' || c == '\r')
        {
            // if(0)
            if (response.indexOf(rec_head) != -1)
            {

                range_analy(response);

                // Serial.println("-----------Get range msg-----------");

                // String result = response.substring(response.indexOf(rec_head) + rec_head.length());

                // Serial.println(result);
                // Serial.println("-----------Over-----------");
            }
            else
            {
                Serial.println(response);
            }

            response = "";
        }
        else
            response += c;
    }
}

// SSD1306

void logoshow(void)
{
    display.clearDisplay();

    display.setTextSize(2);              // Normal 1:1 pixel scale
    display.setTextColor(SSD1306_WHITE); // Draw white text
    display.setCursor(0, 0);             // Start at top-left corner
    display.println(F("Get Range"));

    // display.setTextSize(1);
    display.setCursor(0, 20);
    display.println(F("JSON"));
    display.setCursor(0, 40);
    display.println(F("A0"));
    display.display();
    delay(2000);
}

// AT+RANGE=tid:1,mask:04,seq:63,range:(0,0,30,0,0,0,0,0),rssi:(0.00,0.00,-77.93,0.00,0.00,0.00,0.00,0.00)

void range_analy(String data)
{
    String id_str = data.substring(data.indexOf("tid:") + 4, data.indexOf(",mask:"));
    String range_str = data.substring(data.indexOf("range:"), data.indexOf(",rssi:"));
    String rssi_str = data.substring(data.indexOf("rssi:"));

    // Serial.println(id_str);
    // Serial.println(range_str);
    // Serial.println(rssi_str);

    // range:(0,0,51,0,0,0,0,0)
    // rssi:(0.00,0.00,-78.54,0.00,0.00,0.00,0.00,0.00)

    int range_list[8];
    double rssi_list[8];
    int count = 0;

    count = sscanf(range_str.c_str(), "range:(%d,%d,%d,%d,%d,%d,%d,%d)",
                   &range_list[0], &range_list[1], &range_list[2], &range_list[3],
                   &range_list[4], &range_list[5], &range_list[6], &range_list[7]);

    if (count != 8)
    {
        Serial.println("RANGE ANALY ERROR");
        Serial.println(count);
        return;
    }

    count = sscanf(rssi_str.c_str(), "rssi:(%lf,%lf,%lf,%lf,%lf,%lf,%lf,%lf)",
                   &rssi_list[0], &rssi_list[1], &rssi_list[2], &rssi_list[3],
                   &rssi_list[4], &rssi_list[5], &rssi_list[6], &rssi_list[7]);

    if (count != 8)
    {
        Serial.println("RSSI ANALY ERROR");
        Serial.println(count);
        return;
    }

    // Serial Port
    // Serial.print("TAG ");
    // Serial.println(id_str);
    // for (int i = 0; i < 8; i++)
    // {
    //     Serial.print("A");
    //     Serial.print(i);
    //     Serial.print(" RANGE ");
    //     Serial.print(range_list[i]);
    //     Serial.print(" RSSI ");
    //     Serial.println(rssi_list[i]);
    // }

    // Serial Port Json
    String json_str = "";
    json_str = json_str + "{\"id\":" + id_str + ",";
    json_str = json_str + "\"range\":[";
    for (int i = 0; i < 8; i++)
    {
        if (i != 7)
            json_str = json_str + range_list[i] + ",";
        else
            json_str = json_str + range_list[i] + "]}";
    }

    Serial.println(json_str);
}

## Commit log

2024-03-12 Create project
    [ESP32-S3 AT UWB Pro with Display v1.0.brd, ESP32-S3 AT UWB Pro with Display v1.0.sch]
2024-03-12 Add pdf
    [ESP32-S3 AT UWB Pro with Display v1.0.brd, ESP32-S3 AT UWB Pro with Display v1.0.sch]
2024-11-13 updata code
    修改了at指令设置不成功的问题
2025-02-08 添加了python文件
2025-02-21 添加传输数据例程
2025-02-21 Update esp32s3_data_a0.ino
    解除了传输数据a0的屏蔽部分
2025-02-27 Update
    添加两条新AT指令
2026-05-14 Create MaUWB ESP32-S3 AT UWB Pro with Display v1.2.brd
    Add layout
    [MaUWB ESP32-S3 AT UWB Pro with Display v1.2.brd]
2026-05-14 Add layout
    [MaUWB ESP32-S3 AT UWB Pro with Display v1.2.brd]
